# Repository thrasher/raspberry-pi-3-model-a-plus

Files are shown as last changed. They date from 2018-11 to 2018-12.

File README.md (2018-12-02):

# Raspberry Pi 3 Model A+

Assembled Parts in Default Configuration

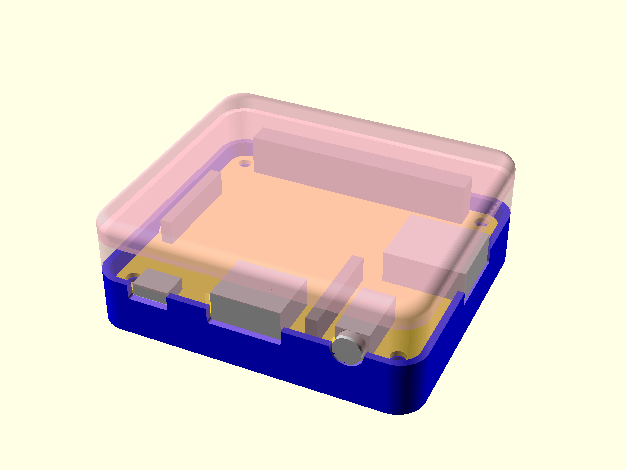
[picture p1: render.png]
OpenSCAD render of case STL


Lid

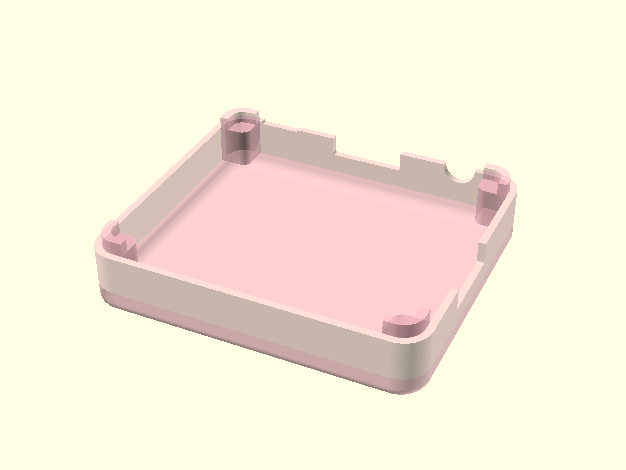
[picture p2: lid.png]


Simple Case

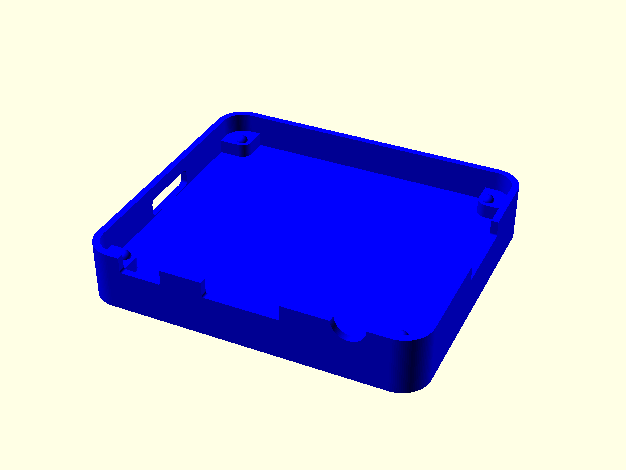
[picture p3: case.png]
OpenSCAD render of case STL


VESA-75 Case

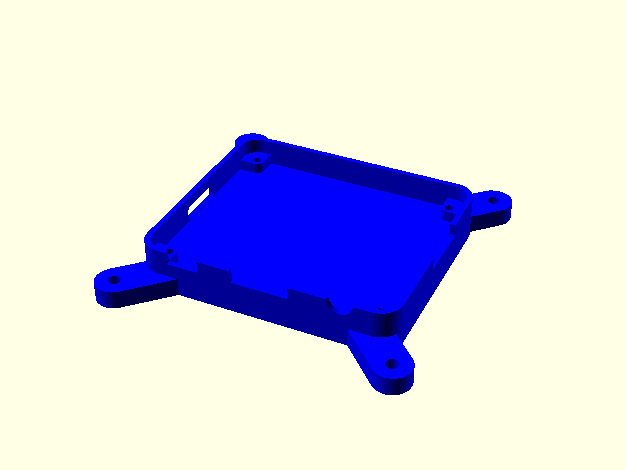
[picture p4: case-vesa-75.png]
OpenSCAD render of VESA-75 case STL


VESA-100 Case

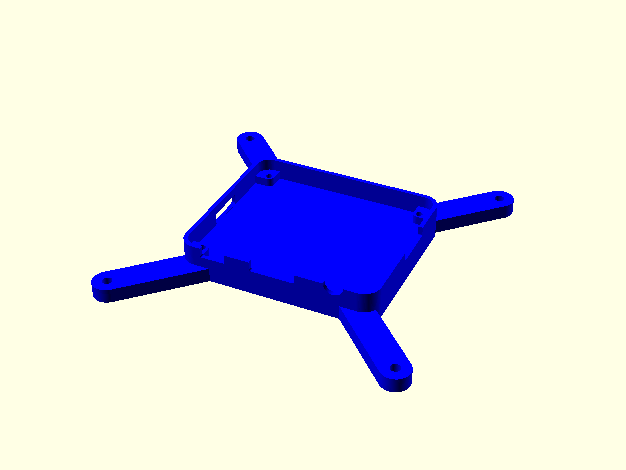
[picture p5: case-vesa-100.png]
OpenSCAD render of VESA-100 case STL


Raspberry Pi 3 Model A+ Model.  This part is useful to gauge fitment for a case.  Dimensions are +/- 0.05 mm

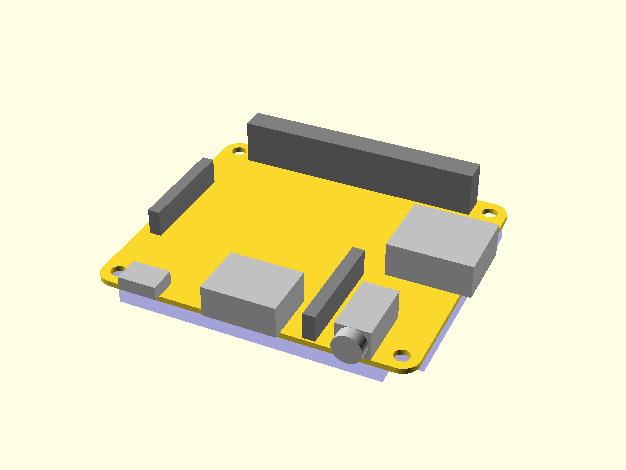
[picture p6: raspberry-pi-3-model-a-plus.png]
OpenSCAD render of Raspberry Pi 3 Model A+ STL


## Summary

Simple cases for a [Raspberry Pi 3 Model A+](https://www.raspberrypi.org/products/raspberry-pi-3-model-a-plus/).

The VESA cases allow for mounting to the back of a monitor using M4 screws.

## Print Settings

Dimensions are in millimeters.

## Post-Printing

Clean off any raft or supports with a knife.
Use a hand-drill to even out the holes with appropriately sized drill bits.

## How I Designed This

OpenSCAD

## References

1. https://www.thingiverse.com/thing:3220994
1. https://github.com/thrasher/raspberry-pi-3-model-a-plus

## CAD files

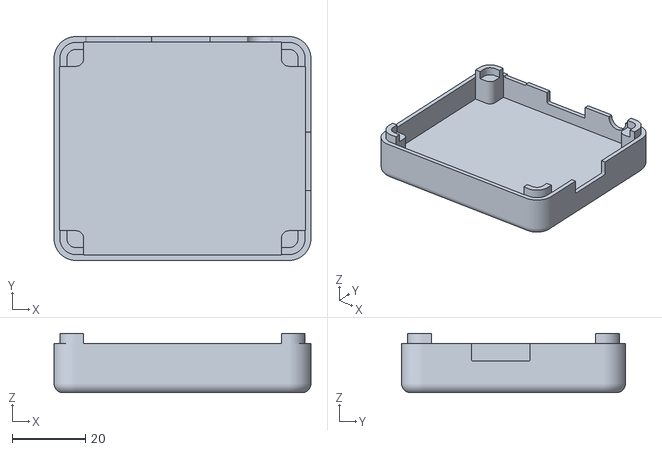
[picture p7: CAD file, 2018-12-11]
lid.stl
70.0 x 61.0 x 16.2

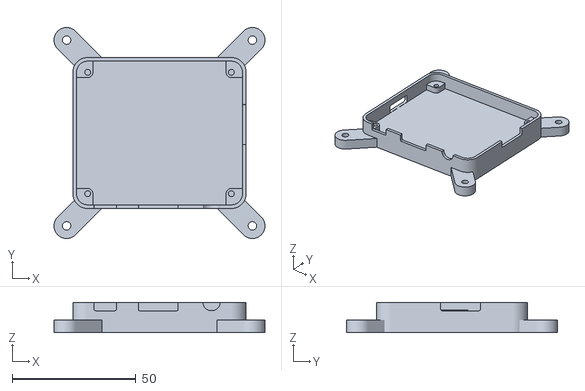
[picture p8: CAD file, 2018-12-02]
case-vesa-75.stl
85.2 x 85.2 x 12.2

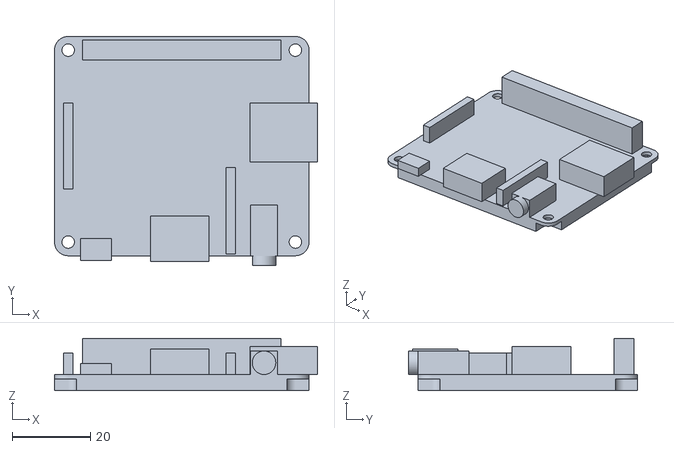
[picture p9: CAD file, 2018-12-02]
raspberry-pi-3-model-a-plus.stl
67.2 x 58.5 x 13.4

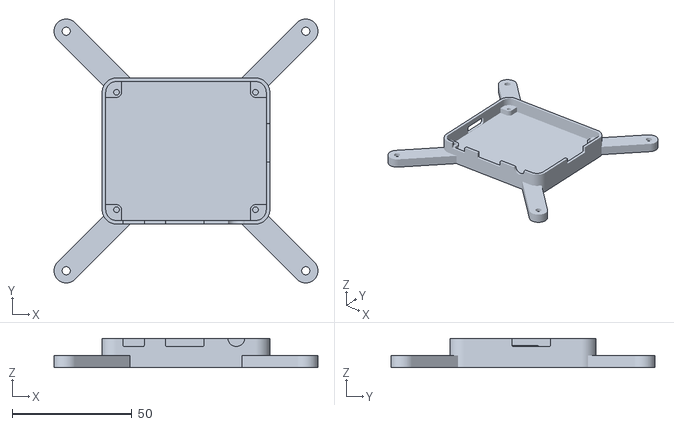
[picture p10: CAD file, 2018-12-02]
case-vesa-100.stl
110.2 x 110.2 x 12.2

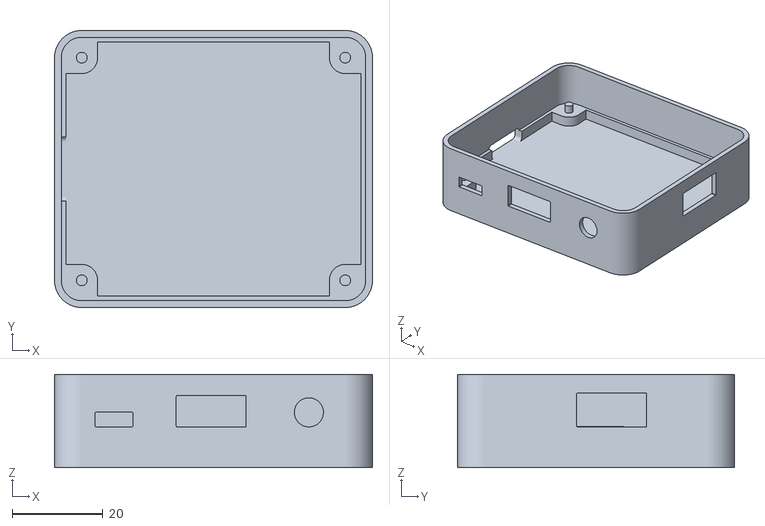
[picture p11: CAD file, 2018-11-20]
case.stl
70.0 x 61.0 x 20.5

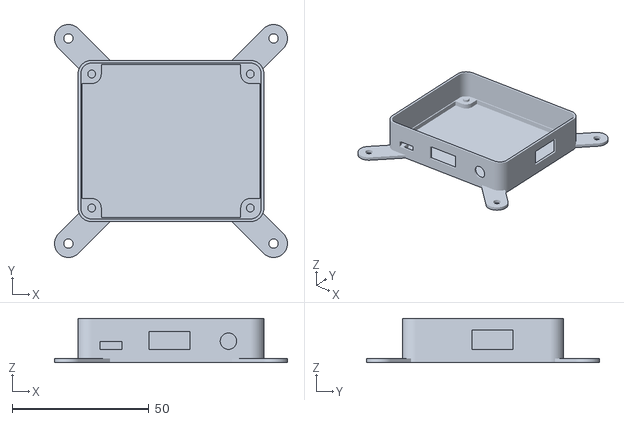
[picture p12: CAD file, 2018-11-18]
case-vesa.stl
85.2 x 85.2 x 16.2

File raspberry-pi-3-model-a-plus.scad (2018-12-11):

// raspberry-pi-3-model-a-plus
// Nov 16, 2018
// author: Jason Thrasher
//
// This is a rough drawing of a Raspberry Pi 3 A+.
// It is suitable for use in 3D printing or case layouts.
//
// part reference
// https://www.raspberrypi.org/products/raspberry-pi-3-model-a-plus/
// dimensions taken from mechanical drawing and Raspbery Pi 3 B+ caliper measurements
// https://www.raspberrypi.org/app/uploads/2018/11/Raspberry_Pi_3A_mechanical-drawing.pdf
//
// Dimensions in millimeters

$fs = 0.1; // mm per facet in cylinder
$fa = 5; // degrees per facet in cylinder
$fn = 100;


BOARD_CORNER_R = 3.5;
BOARD_THICKNESS = 1.15; // 1.15 as measured on Raspberry Pi 3 Model B+
MOUNTING_HOLE_DIA = 0.125 * 25.4; // convert inches to mm
BOARD_W = 65; // 3A+ drawing
BOARD_H = 56; // 3A+ drawing
HOLE_W = 58;
HOLE_H = 49;
UNDERSIDE_DEPTH = 3; // clearence required by 3B+: 2.2
WARP_OFFSET = 0.15;

// layout children relative to each mounting hole
module mounting_layout() {
		children();
		translate([HOLE_W, 0, 0])
		rotate(90)
		children();
		translate([HOLE_W, HOLE_H, 0])
		rotate(180)
		children();
		translate([0, HOLE_H, 0])
		rotate(270)
		children();
}

module board_2d_positive(RADIUS = 10) {
		mounting_layout() circle(r = RADIUS);
}

module board_2d() {
	difference() {
		hull()
		board_2d_positive(BOARD_CORNER_R);
		board_2d_positive(MOUNTING_HOLE_DIA/2);
	}
}

module board() {
	linear_extrude(height = BOARD_THICKNESS)
	board_2d();
}

module  pin_header() {
	// from 3B+ pin header: 5.1 x 50.7 x 10.4-BOARD_THICKNESS
	H = 10.4-BOARD_THICKNESS;
	translate([29, HOLE_H, H/2 + BOARD_THICKNESS])
	cube([50.7, 5.1, H ], center = true);
}

module DSI_display_port() {
	// from 3B+ pin header: 22 x 2.5 x 6.9-BOARD_THICKNESS
	// height specified in 3A+ drawing: 5.5
	H = 5.5;

	translate([0, -BOARD_CORNER_R, BOARD_THICKNESS])
	translate([0, 28, H/2])
	rotate([0,0,90])
	cube([22, 2.5, H ], center = true);
}

module CSI_camera_port() {
	// from 3B+ pin header: 22.1 x 2.5 x 6.9-BOARD_THICKNESS
	// height specified in 3A+ drawing: 5.5
	H = 5.5;
	translate([ -BOARD_CORNER_R, -BOARD_CORNER_R, BOARD_THICKNESS])
	translate([45, 11.5, H/2])
	rotate([0,0,90])
	cube([22.1, 2.5, H ], center = true);
}

module usb_port(DO_CUTOUT = false) {
	// from 3B+ usb: width: 15, depth: 17.25
	W = 15;
	D = 17.25;
	H = 7.1; // height specified in 3A+ drawing: 7.1
	OVERHANG = 2.15; // board USB overhang measured from 3B+: 2.15;

	translate([ -BOARD_CORNER_R, -BOARD_CORNER_R, BOARD_THICKNESS])
	translate([65 - D/2 + OVERHANG, 31.45, H/2])
	union() {
		cube([D, W, H ], center = true);

		// properly oriented case cutout
		if (DO_CUTOUT) {
			CUTOUT_MARGIN = 0.5;
			port_cutout(W + CUTOUT_MARGIN*2, H + CUTOUT_MARGIN*2, CUTOUT_MARGIN);
		}
	}
}

module audio_port(DO_CUTOUT = false) {
	W = 7;
	D_PORT = 2.5; // round port dia measured from 3B+
	D = 15.5; // overall port depth measured from 3B+
	H = 6; // diameter of port measured from 3B+

	OVERHANG = 2.15; // board USB overhang measured from 3B+: 2.15;

	translate([ -BOARD_CORNER_R + BOARD_W, -BOARD_CORNER_R, BOARD_THICKNESS])
	translate([-11.5, (D-D_PORT)/2, H/2])
	rotate([0,0,-90])
	//translate([D/2,0,0])
	union() {
		cube([D - D_PORT, W, H ], center = true);
		translate([D/2,0,0])
		rotate([0,90,0])
		cylinder(d = H, h = D_PORT, center = true);
		// case cutout
		if (DO_CUTOUT) {
			// port_cutout(0, 0, D_PORT/2 + 0.3);
			CUTOUT_MARGIN = 0.5 + H/2;
			port_cutout(CUTOUT_MARGIN*2, CUTOUT_MARGIN*2, CUTOUT_MARGIN);
		}
	}
}

module hdmi_port(DO_CUTOUT = false) {
	// from 3B+ usb: width: 15, depth: 17.25
	W = 15;
	D = 11.7;
	H = 6.5; // height specified in 3A+ drawing: 7.1
	OVERHANG = 1.5; // board USB overhang measured from 3B+: 1.5

	translate([ -BOARD_CORNER_R, -BOARD_CORNER_R, BOARD_THICKNESS])
	translate([32, D/2-OVERHANG, H/2])
	rotate([0,0,-90])
	union() {
		cube([D, W, H ], center = true);
		// properly oriented case cutout
		if (DO_CUTOUT) {
			CUTOUT_MARGIN = 0.5;
			port_cutout(W + CUTOUT_MARGIN*2, H + CUTOUT_MARGIN*2, CUTOUT_MARGIN);
		}
	}
}

module mini_usb_port(DO_CUTOUT = false) {
	// from 3B+ usb: width: 15, depth: 17.25
	W = 8;
	D = 5.6;
	H = 4 - BOARD_THICKNESS; // measured from 3B+
	OVERHANG = 1.25; // board USB overhang measured from 3B+

	translate([ -BOARD_CORNER_R, -BOARD_CORNER_R, BOARD_THICKNESS])
	translate([10.6, D/2-OVERHANG, H/2])
	rotate([0,0,-90])
	union() {
		cube([D, W, H ], center = true);
		// properly oriented case cutout
		if (DO_CUTOUT) {
			CUTOUT_MARGIN = 0.5;
			port_cutout(W + CUTOUT_MARGIN*2, H + CUTOUT_MARGIN*2, CUTOUT_MARGIN);
		}
	}
}

module sdcard_slot(DO_CUTOUT = false) {
	// note: inserted card sticks out 2.5mm from edge of G10
	// from 3B+ usb: width: 15, depth: 17.25
	W = 12;
	D = 11.5;
	H = 1.5 + 0.5; // measured from 3B+ as 1.5, but card adds 0.5
	OVERHANG = -1.5; // board USB overhang measured from 3B+

	translate([ -BOARD_CORNER_R, -BOARD_CORNER_R, -H/2])
	translate([D/2 - OVERHANG, BOARD_H/2, 0])
	rotate([0,0,180])
	union() {
		cube([D, W, H], center = true);

		// properly oriented case cutout
		if (DO_CUTOUT) {
			CUTOUT_MARGIN = 1;
			port_cutout(W + CUTOUT_MARGIN*2, H + CUTOUT_MARGIN*2, CUTOUT_MARGIN);
		}
	}
}

module port_cutout(W, H, CUT_RADIUS = 0.2) {
	// CUT_RADIUS = 0.2;
	CUT_WIDTH = W - CUT_RADIUS*2;
	CUT_HEIGHT = H - CUT_RADIUS*2;
	CUT_DEPTH = 30;

	translate([CUT_DEPTH/2,0,0])
	rotate([0,90,0])
	hull() {
		CW = CUT_WIDTH/2;
		CH = CUT_HEIGHT/2;

		translate([-CH,-CW,0])
		cylinder(r = CUT_RADIUS, h = CUT_DEPTH, center = true);
		translate([CH,CW,0])
		cylinder(r = CUT_RADIUS, h = CUT_DEPTH, center = true);
		translate([-CH,CW,0])
		cylinder(r = CUT_RADIUS, h = CUT_DEPTH, center = true);
		translate([CH,-CW,0])
		cylinder(r = CUT_RADIUS, h = CUT_DEPTH, center = true);
	}
}

module mounting_post(INTERIOR_EDGE = BOARD_CORNER_R + CASE_PI_CLEARENCE) {
	// difference() {
		hull() {
			QUARTER = BOARD_CORNER_R * 0.6;
	  	circle(r = QUARTER);

			// translate([-BOARD_CORNER_R,-BOARD_CORNER_R,0])
	  	// square(QUARTER);

			translate([0,-INTERIOR_EDGE,0])
	  	square([QUARTER, INTERIOR_EDGE]);

			translate([-INTERIOR_EDGE,0,0])
	  	square([INTERIOR_EDGE, QUARTER]);

	  	// wall side quarter curve
			difference() {
			  circle(r = INTERIOR_EDGE);
			  square(INTERIOR_EDGE);
				translate([0,-INTERIOR_EDGE,0])
			  square(INTERIOR_EDGE);
				translate([-INTERIOR_EDGE,0,0])
			  square(INTERIOR_EDGE);
			}
	  }
	  // hole to screw into
	 //  circle(d = MOUNTING_HOLE_DIA*.75);
  // }

}

module mounting_posts(INTERIOR_EDGE = BOARD_CORNER_R + CASE_PI_CLEARENCE) {
	mounting_layout() mounting_post(INTERIOR_EDGE);
}
// clearence for solder joints or components on underside of board
module underside_clearence() {
	translate([0,0,-UNDERSIDE_DEPTH])
	linear_extrude(height = UNDERSIDE_DEPTH)
	difference() {
		board_2d();
		mounting_posts();
	}
}

module components(DO_CUTOUT = false) {
	color("grey") pin_header();
	color("grey") DSI_display_port();
	color("grey") CSI_camera_port();
	color("silver") usb_port(DO_CUTOUT);
	color("silver") audio_port(DO_CUTOUT);
	color("silver") hdmi_port(DO_CUTOUT);
	color("silver") mini_usb_port(DO_CUTOUT);
	color("red") sdcard_slot(DO_CUTOUT);
}

module 3Aplus() {
	board();
	components();
	color("blue", alpha = 0.2) underside_clearence();
}

LID_DEPTH = 8.35;
INTERIOR_HEIGHT = 12.5 - LID_DEPTH;
CASE_WALL_THICKNESS = 2.5;
CASE_PI_CLEARENCE = 1.0; // space btw pi edge and case wall
FLOOR_THICKNESS = CASE_WALL_THICKNESS * 2;

module sphere_post() {
	//cylinder(d = MOUNTING_HOLE_DIA * 0.75, h = BOARD_THICKNESS);
	//translate([0,0,BOARD_THICKNESS])
	sphere(d = MOUNTING_HOLE_DIA * .75);
}

module lid() {
	// upper walls
	difference() {
		translate([0,0,INTERIOR_HEIGHT])
		linear_extrude(height = LID_DEPTH, convexity = 2)
		difference() {
			hull() board_2d_positive(BOARD_CORNER_R + CASE_WALL_THICKNESS);
			hull() board_2d_positive(BOARD_CORNER_R + CASE_PI_CLEARENCE);
		}

		// offset to accomodate weird warpage
		translate([0, 0, WARP_OFFSET])
		components(DO_CUTOUT = true);
	}

	// closed top cover
	translate([0,0,INTERIOR_HEIGHT + LID_DEPTH]) {
	hull() {
	linear_extrude(height = 0.1)
	board_2d_positive(BOARD_CORNER_R + CASE_WALL_THICKNESS);
	translate([0,0,FLOOR_THICKNESS/2])
	// hull()
	mounting_layout()
	rotate([0,0,180])
  rotate_extrude(angle = 90, convexity = 100)
  translate([BOARD_CORNER_R + CASE_WALL_THICKNESS - FLOOR_THICKNESS/2, 0, 0])
	circle(d = FLOOR_THICKNESS);
	}
	}

	// locking posts
	difference() {
		union() {
			translate([0,0,INTERIOR_HEIGHT])
			linear_extrude(height = LID_DEPTH, convexity = 2)
			mounting_posts(BOARD_CORNER_R + CASE_PI_CLEARENCE);
			translate([0,0,BOARD_THICKNESS + WARP_OFFSET])
			linear_extrude(height = INTERIOR_HEIGHT - BOARD_THICKNESS - WARP_OFFSET, convexity = 2)
			mounting_posts(BOARD_CORNER_R + CASE_PI_CLEARENCE - 0.1);
		}
		// cutout for screws
		linear_extrude(height = 4, convexity = 2)
		hull()
		board_2d_positive(2.5);
	}
}
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

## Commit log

2018-11-16 created Raspberry Pi 3 Model A+ OpenSCAD model
    [raspberry-pi-3-model-a-plus.scad]
2018-11-16 actual STL output
    [raspberry-pi-3-model-a-plus.stl]
2018-11-17 partial case
    [raspberry-pi-3-model-a-plus.scad]
2018-11-18 created lower case
    [case.stl, raspberry-pi-3-model-a-plus.scad, raspberry-pi-3-model-a-plus.stl]
2018-11-18 added render of case
2018-11-18 added a VESA-75 case
    [case-vesa.stl, case.stl, raspberry-pi-3-model-a-plus.scad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]
2018-11-18 created versions for VESA 75 and 100 mounts
    [case-vesa-100.stl, case-vesa-75.stl, case.stl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]
2018-11-18 add image for vesa mounts
2018-11-18 added sdcard slot
    [raspberry-pi-3-model-a-plus.scad]
2018-11-18 added cutout for sdcard slot in case
    [raspberry-pi-3-model-a-plus.scad]
2018-11-18 added margin cutout to case, so there's some tolerance for shifting around
    [case-vesa-100.stl, case-vesa-75.stl, case.stl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]
2018-11-20 change peg dia to fit G10 holes better
    [raspberry-pi-3-model-a-plus.scad]
2018-11-20 changed wall spacing and thickness to accomodate PLA warping on print
    [case-vesa-100.stl, case-vesa-75.stl, case.stl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]
2018-11-20 fixing error in VESA feet offset from floor
    [case-vesa-100.stl, case-vesa-75.stl, case.stl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]
2018-11-30 partial wall height, to clear socketed components, refactored for screw or post mount
    [case-vesa-100.stl, case-vesa-75.stl, raspberry-pi-3-model-a-plus.scad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]
2018-12-01 added lid, increased space around exterior connectors, refined posts so lower margin isn't needed
    [case-vesa-100.stl, case-vesa-75.stl, lid.stl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]
2018-12-02 Added rounded corners to lid, added offset to account for warp errors from PLA printing (vertical spacing), made default print mode for mounting holes, made lid locking corners slightly smaller to ma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
    [case-vesa-100.stl, case-vesa-75.stl, lid.stl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]
2018-12-11 cutout lid to clear internal PCB mounting screws w/4mm dia heads
    [lid.stl, raspberry-pi-3-model-a-plus.scad]
